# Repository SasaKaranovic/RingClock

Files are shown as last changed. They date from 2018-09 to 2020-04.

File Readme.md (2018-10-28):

# My New RingClock

I wanted to build myself a cool clock that would look nice, be different and make absolutely no sound. And so I did. 

Check out [this post to see how I did it](https://sasakaranovic.com/projects/ringclock/)

### Driver Board


### Here it is in action (sorry for poor quality)


Few things that would help you read time from this clock:

- RED led is hour hand
- GEEN led is minute hand
- YELLOW leds are fixed and they show hour markers (12, 1, 2 and etc)
- Elapsed minutes will be "filled" with rainbow colors that rotate over time

Now with that, you can see that clock is showing 4:55

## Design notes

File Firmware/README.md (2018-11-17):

# My New RingClock

I wanted to build myself a cool clock that would look nice, be different and make absolutely no sound. And so I did. 

Check out [this post to see how I did it](https://sasakaranovic.com/projects/ringclock/)

# Requirements

In order to compile this firmware, you will need:
- [ARM GCC compiler](https://developer.arm.com/open-source/gnu-toolchain/gnu-rm/downloads) installed and added to your system environment variables (if you are using windows)
- Programer to flash the compiled firmware onto the board (ST-Link or JLink)

# Compiling the firmware
Open your command prompt or terminal and navigate to Firmware folder (this one).
Start compiling the firmware by typing `make all`
After it's complete you should see something like

```
arm-none-eabi-size RingClock.elf
   text    data     bss     dec     hex filename
  39976    1108    5096   46180    b464 RingClock.elf
```

This should mean that you successfully compiled the firmware.

# Flashing the firmware onto the board
Depending which programmer you are using, you can either use provided GUI app
to flash the firmware (STM32 ST-LINK Utility or J-Flash). I personally prefer  doing
this through console so I've added two options to the make file that allow you to flash
firmware onto the board by calling  `make flash` for ST-Link  or `make jlink` for J-Link programmer.

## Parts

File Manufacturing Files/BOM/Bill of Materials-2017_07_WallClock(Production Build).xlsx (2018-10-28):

Designator | Manufacturer | Manufacturer Part Number | Distributor | Distributor Part Number | Value | Quantity
BT1 | MPD (Memory Protection Devices) | BK-883-TR | DigiKey | BK-883-CT-ND |  | 1
C1, C2, C3, C4, C5, C6, C7, C14, C16, C17, C18, C19, C21 | Samsung Electro-Mechanics | CL10A104KA8NNNC | DigiKey | 1276-1857-1-ND | 100n | 13
C8, C9 | AVX Corporation | 06031A120JAT4A | DigiKey | 478-10188-1-ND | 12p | 2
C15, C20, C22 | Samsung Electro-Mechanics | CL21A226MOCLRNC | DigiKey | 1276-6780-1-ND | 22u | 3
CN1 | Amphenol FCI | 10118192-0001LF | DigiKey | 609-4613-1-ND |  | 1
D1 | Inolux | IN-S63AT5A | DigiKey | 1830-1064-1-ND |  | 1
D2 | OSRAM Opto Semiconductors Inc. | LW Q38G-Q1OO-3K6L-1 | DigiKey | 475-2832-1-ND |  | 1
L1 | Murata Electronics North America | BLM18PG221SN1D | DigiKey | 490-5221-1-ND |  | 1
P3 | EDAC Inc. | 690-005-299-043 | DigiKey | 151-1206-1-ND |  | 1
R3, R4, R5, R6, R7, R8 | Yageo | RC0603JR-071KL | DigiKey | 311-1.0KGRCT-ND | 1K | 6
R11 | Yageo | RC0603JR-070RL | DigiKey | 311-0.0GRCT-ND | 0R | 1
SW1, SW2 | C&K | PTS645SL50SMTR92 LFS | DigiKey | CKN9088CT-ND |  | 2
U1 | STMicroelectronics | STM32F103C8T6 | DigiKey | 497-6063-ND |  | 1
U2 | Diodes Incorporated | AP2127K-3.3TRG1 | DigiKey | AP2127K-3.3TRG1DICT-ND |  | 1
Y1 | Abracon LLC | ABS07-120-32.768KHZ-T | DigiKey | 535-11937-1-ND |  | 1

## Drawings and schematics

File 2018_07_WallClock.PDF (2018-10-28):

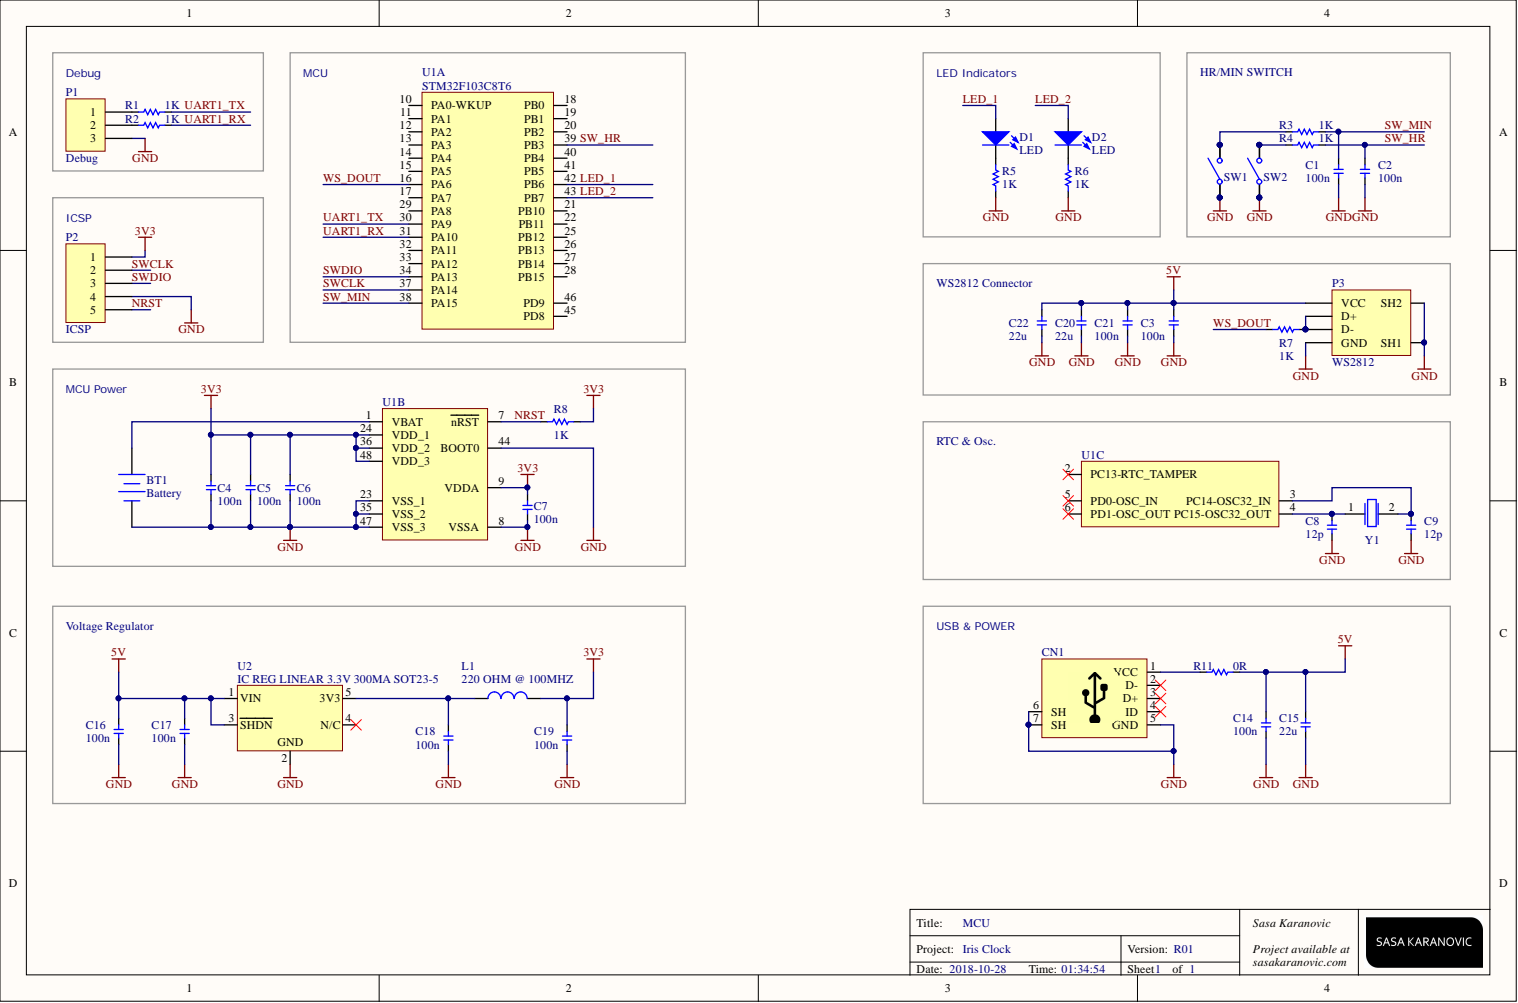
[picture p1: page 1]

BT 1 Bat tery | C4 | C5 | C6 | 4 | 8 | 3 V 3 C7 1 0 0 n

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

Project : Iri s Cl ock | Vers i o n : R0 1
Date: 2 0 1 8-1 0-2 8 T ime: 0 1 : 3 4 : 5 4 | Sheet 1 o f 1

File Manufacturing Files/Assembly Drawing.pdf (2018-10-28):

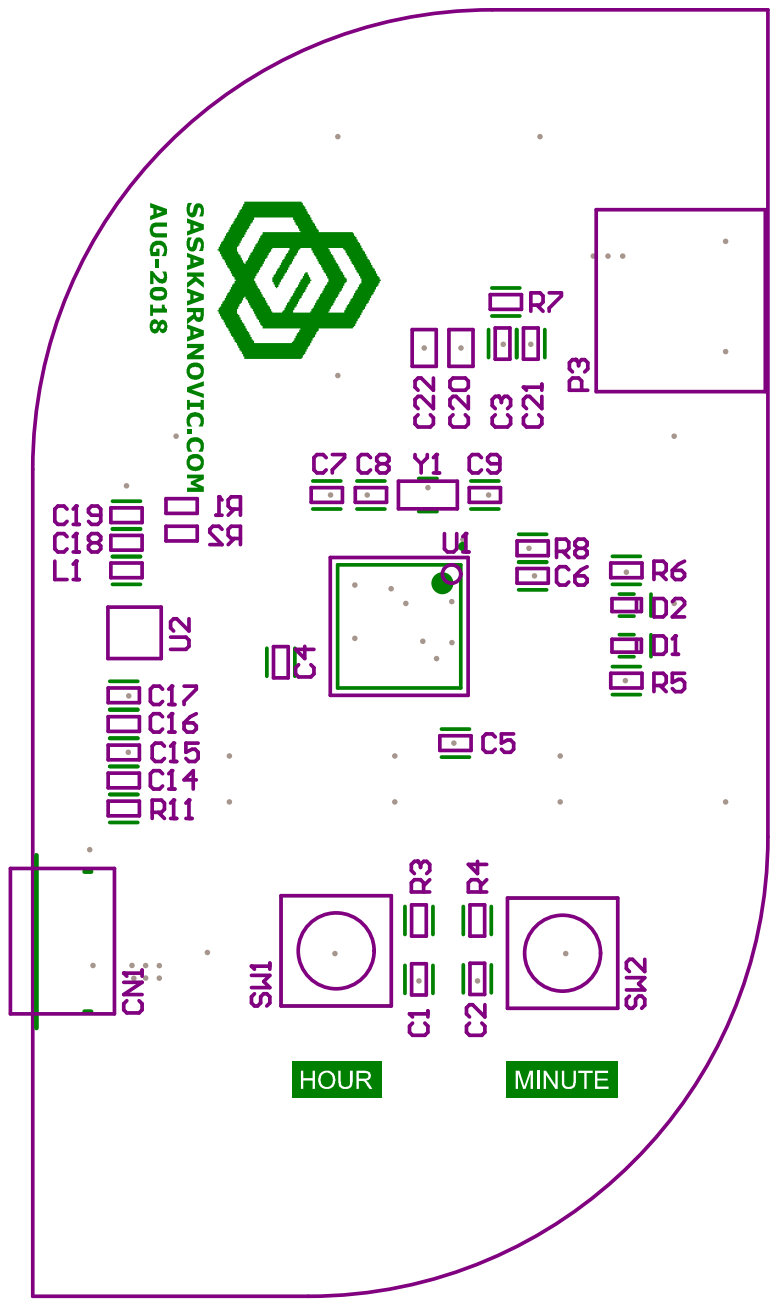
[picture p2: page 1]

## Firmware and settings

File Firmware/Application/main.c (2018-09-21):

// C99
#include <stdint.h>

// HAL
#include "stm32f1xx.h"


// App
#include "sys_init.h"
#include "clock_config.h"
#include "clock.h"
#include "debug.h"
#include "rtc.h"

#define periodReadRTC                   20000

// Clock variables
uint8_t clockHours                      = 0;
uint8_t clockMinutes                    = 0;
uint8_t clockSeconds                    = 0;

// Various variables
volatile uint32_t miliseconds           = 0;
volatile uint32_t updateTime            = 0;
volatile uint32_t updateLED             = 0;
volatile uint32_t periodUpdateClock     = LED_UPDATE_SPEED_FAST;

extern RTC_HandleTypeDef hrtc;

uint8_t brightness = 0;


int main(void)
{
    Sys_Init();

    DebugLED_On();
    UserLED_On();

    debug_log("WallClock Up&Running\r\n");
    // RTC_SetTime(20, 50, 0);
    RTC_ReadTime(&clockHours, &clockMinutes, &clockSeconds);
    HAL_Delay(500);
    DebugLED_Off();
    UserLED_Off();

    // Loop forever
    while (1){

        // Update LEDs and cycle colors
        if(miliseconds >= updateLED)
        {
            DebugLED_On();
            Clock_Update(clockHours, clockMinutes);
            updateLED = miliseconds + periodUpdateClock        DebugLED_Off();
        }

        // Read time from RTC and update local variables
        if(miliseconds >= updateTime)
        {
            RTC_ReadTime(&clockHours, &clockMinutes, &clockSeconds);
            debug("Debug: %02d:%02d:%02d", clockHours, clockMinutes, clockSeconds);
            updateTime = miliseconds + periodReadRTC;
        }

        // Read Hour/Minute butons
        while(BUTTON_ReadHR() || BUTTON_ReadMIN())
        {
            // Wait about 200ms to detect both button pressed event. Also act as SWd debounce
            UserLED_On();
            HAL_Delay(150);

            if( BUTTON_ReadHR() && BUTTON_ReadMIN() )
            {
                switch(Clock_GetMode())
                {
                    case ModeSameColor:
                        Clock_SetMode(ModeRainbowStatic);
                        periodUpdateClock = LED_UPDATE_SPEED_SLOW;
                    break;

                    case ModeRainbowStatic:
                        Clock_SetMode(ModeRainbowDynamic);
                        periodUpdateClock = LED_UPDATE_SPEED_FAST;
                    break;

                    case ModeRainbowDynamic:
                        Clock_SetMode(ModeSameColor);
                        periodUpdateClock = LED_UPDATE_SPEED_SLOW;
                    break;

                    default:
                        Clock_SetMode(ModeSameColor);
                        periodUpdateClock = LED_UPDATE_SPEED_SLOW;
                    break;
                }
            }
            else
            {
                //Increment hours
                if(BUTTON_ReadHR())
                {
                    clockHours = (clockHours < 23) ? ++clockHours : 0;
                    RTC_SetTime(clockHours, clockMinutes, 0);
                }
                else if(BUTTON_ReadMIN())
                {
                    clockMinutes = (clockMinutes < 59) ? ++clockMinutes : 0;
                    RTC_SetTime(clockHours, clockMinutes, 0);
                }

                // Update LEDs
                Clock_Update(clockHours, clockMinutes);
                
                //Wait for both buttons to be released
                while(BUTTON_ReadHR() || BUTTON_ReadMIN());

                //Software debounce
                UserLED_Off();
                
            }

        }

    }
}


void HAL_SYSTICK_Callback(void)
{
    miliseconds++;
}

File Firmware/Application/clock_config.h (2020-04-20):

#ifndef __CLOCK_CONFIG_H__
#define __CLOCK_CONFIG_H__

// Clock related hard-coded values
#define LED_COUNT               60      // Number of LEDs we have 
#define LED_OFFSET              30      // Position of 12HR LED, counting CCW from your first DIN LED
#define LED_UPDATE_SPEED_SLOW   3000
#define LED_UPDATE_SPEED_FAST   100
#define DIMMING_FEATURE_ENABLED         // Comment this line to disable LED time-based dimming

#define DIM_HOUR_TURN_ON        19      // Turn ON dim feature at 19:00
#define DIM_HOUR_TURN_MAX       22      // This is quiet time. Minimum light
#define DIM_HOUR_TURN_OFF       8       // Turn OFF dim feature at 08:00

#define DIM_LED_IS_ON           0.15
#define DIM_LED_IS_DIM          0.07
#define DIM_LED_IS_MAX          0.01
    
// GPIO definitions 
#define GPIO_MINUTE_PIN         GPIO_PIN_3
#define GPIO_MINUTE_PORT        GPIOB
    
#define GPIO_HOUR_PIN           GPIO_PIN_15
#define GPIO_HOUR_PORT          GPIOA
    
#define GPIO_WS2812_PIN         GPIO_PIN_6
#define GPIO_WS2812_PORT        GPIOA
    
#define GPIO_DBG_LED_PIN        GPIO_PIN_6
#define GPIO_DBG_LED_PORT       GPIOB
    
#define GPIO_USR_LED_PIN        GPIO_PIN_7
#define GPIO_USR_LED_PORT       GPIOB


// Convenience macros and definitions
#define BUTTON_ReadHR()     (!HAL_GPIO_ReadPin(GPIO_HOUR_PORT,   GPIO_HOUR_PIN))
#define BUTTON_ReadMIN()    (!HAL_GPIO_ReadPin(GPIO_MINUTE_PORT, GPIO_MINUTE_PIN))

#ifdef DEBUG_BUILD

#define DebugLED_On()       (HAL_GPIO_WritePin(GPIO_DBG_LED_PORT, GPIO_DBG_LED_PIN, GPIO_PIN_SET))
#define DebugLED_Off()      (HAL_GPIO_WritePin(GPIO_DBG_LED_PORT, GPIO_DBG_LED_PIN, GPIO_PIN_RESET))
#define DebugLED_Toggle()   (HAL_GPIO_TogglePin(GPIO_DBG_LED_PORT, GPIO_DBG_LED_PIN))

#else

#define DebugLED_On()   
#define DebugLED_Off()  
#define DebugLED_Toggle()

#endif

#define UserLED_On()        (HAL_GPIO_WritePin(GPIO_USR_LED_PORT, GPIO_USR_LED_PIN, GPIO_PIN_SET))
#define UserLED_Off()       (HAL_GPIO_WritePin(GPIO_USR_LED_PORT, GPIO_USR_LED_PIN, GPIO_PIN_RESET))
#define UserLED_Toggle()    (HAL_GPIO_TogglePin(GPIO_USR_LED_PORT, GPIO_USR_LED_PIN))

#define UNUSED(x) ((void)(x))

#endif

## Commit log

2018-03-03 RingClock r01
    [stm32f103_stlink.cfg]
2018-08-12 Fast color wheel test.
2018-09-17 Upgrading LED brightness. Update makefile
2018-10-28 RingClock release
    [01_MCU.SchDoc, 2017_07_WallClock.PrjPCB, Bill of Materials-2017_07_WallClock(Production Build).xlsx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]
